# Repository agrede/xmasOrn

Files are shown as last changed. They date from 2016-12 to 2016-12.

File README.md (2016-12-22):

# xmasOrn
Holiday Tree2 Ornament

Tree Ornament with advent calander function. KiCAD files provided and gerber files for making PCB.

## Schematic and Layout
Schematic: [xmasornsch.pdf](https://github.com/agrede/xmasOrn/blob/master/xmasornsch.pdf)
Layout: [xmasornpcb.pdf](https://github.com/agrede/xmasOrn/blob/master/xmasornpcb.pdf)

Resistor values change depending on LED used.

### Minor bugs
The reset button needs to be a normally off switch. Shorting pins removing U2 (NC7WZ14) and shorting the pads for pins 4,5,6 removes the reset.

## Finished Ornament
video demo (http://www.youtube.com/watch?v=HeA6XnS5Pd0)

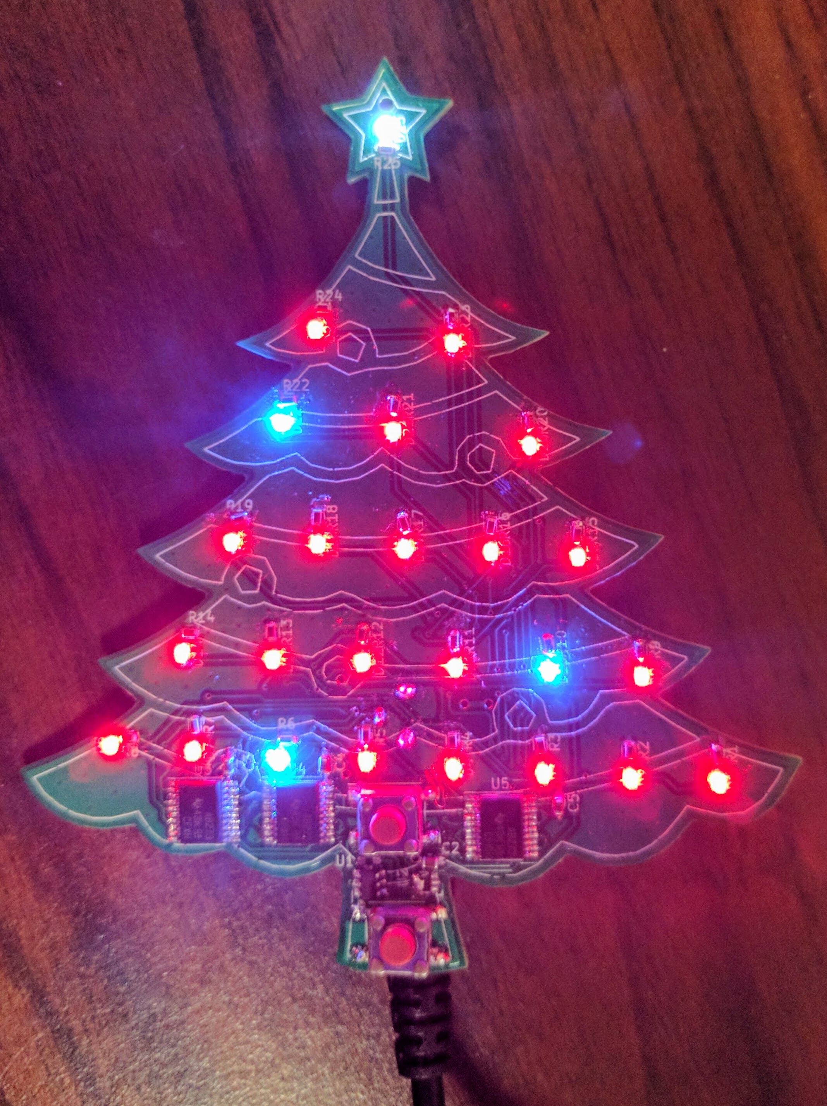
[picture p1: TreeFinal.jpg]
finished ornament


## Licence

<br />This work is licensed under a <a rel="license" href="http://creativecommons.org/licenses/by-sa/4.0/">Creative Commons Attribution-ShareAlike 4.0 International License</a>.

Original Lineart (CC0):
https://pixabay.com/en/christmas-tree-christmas-tree-917749/

3D models, datasheets, etc. are included for convenience

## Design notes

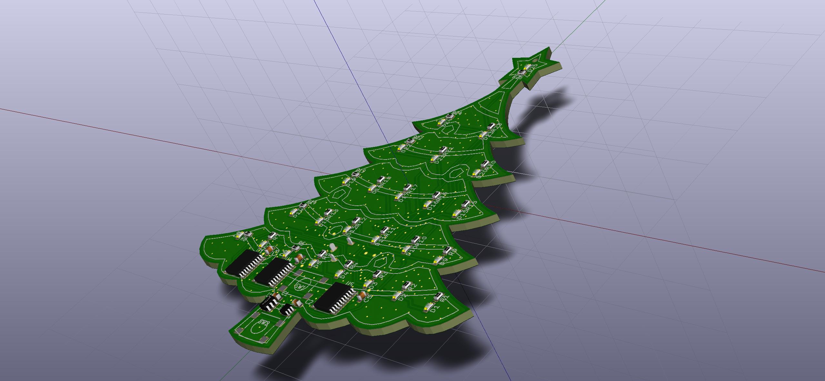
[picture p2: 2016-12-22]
xmasOrn.jpg

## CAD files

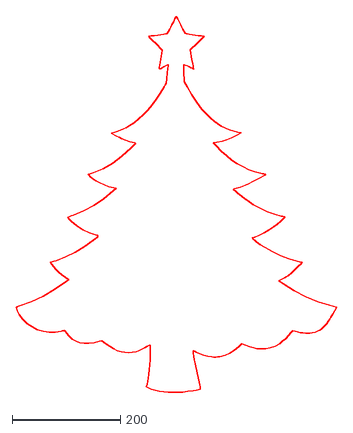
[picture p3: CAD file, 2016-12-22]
christmas-917749.ai.dxf
591.7 x 694.5

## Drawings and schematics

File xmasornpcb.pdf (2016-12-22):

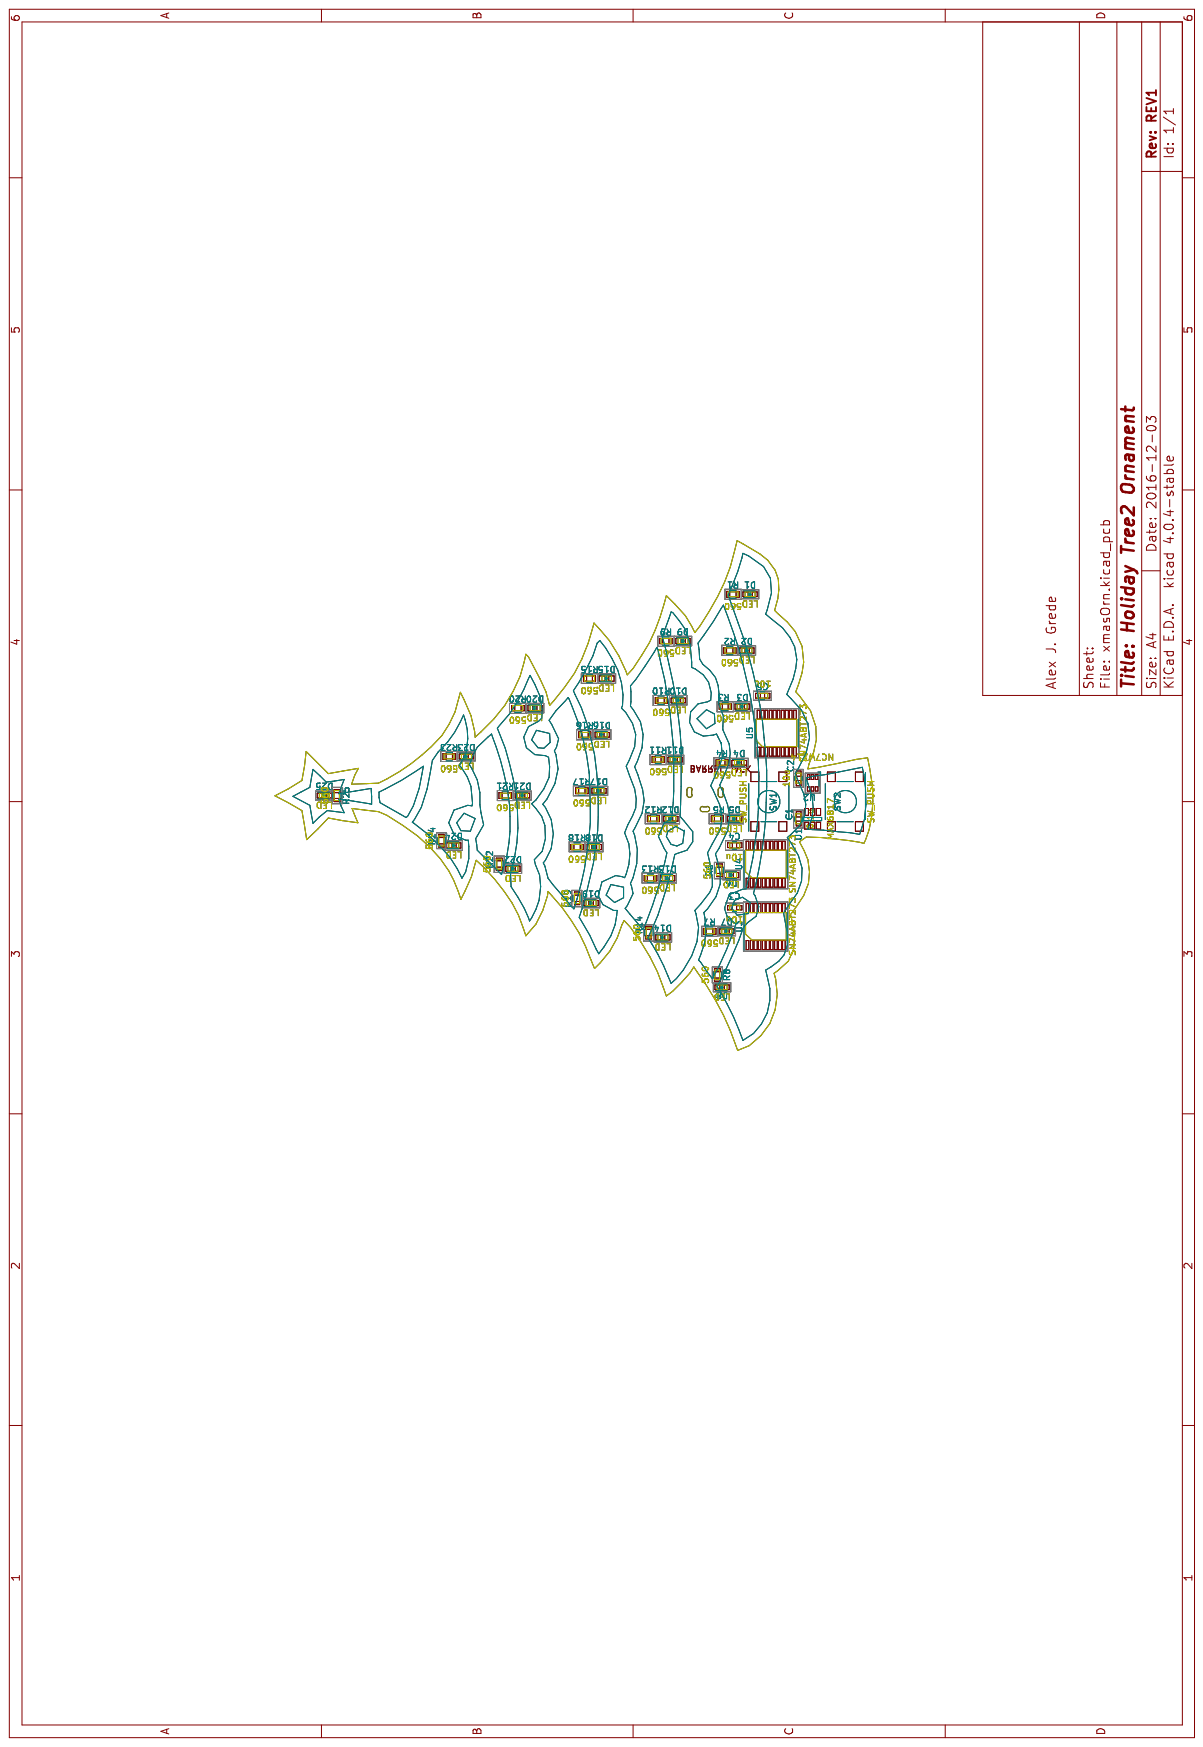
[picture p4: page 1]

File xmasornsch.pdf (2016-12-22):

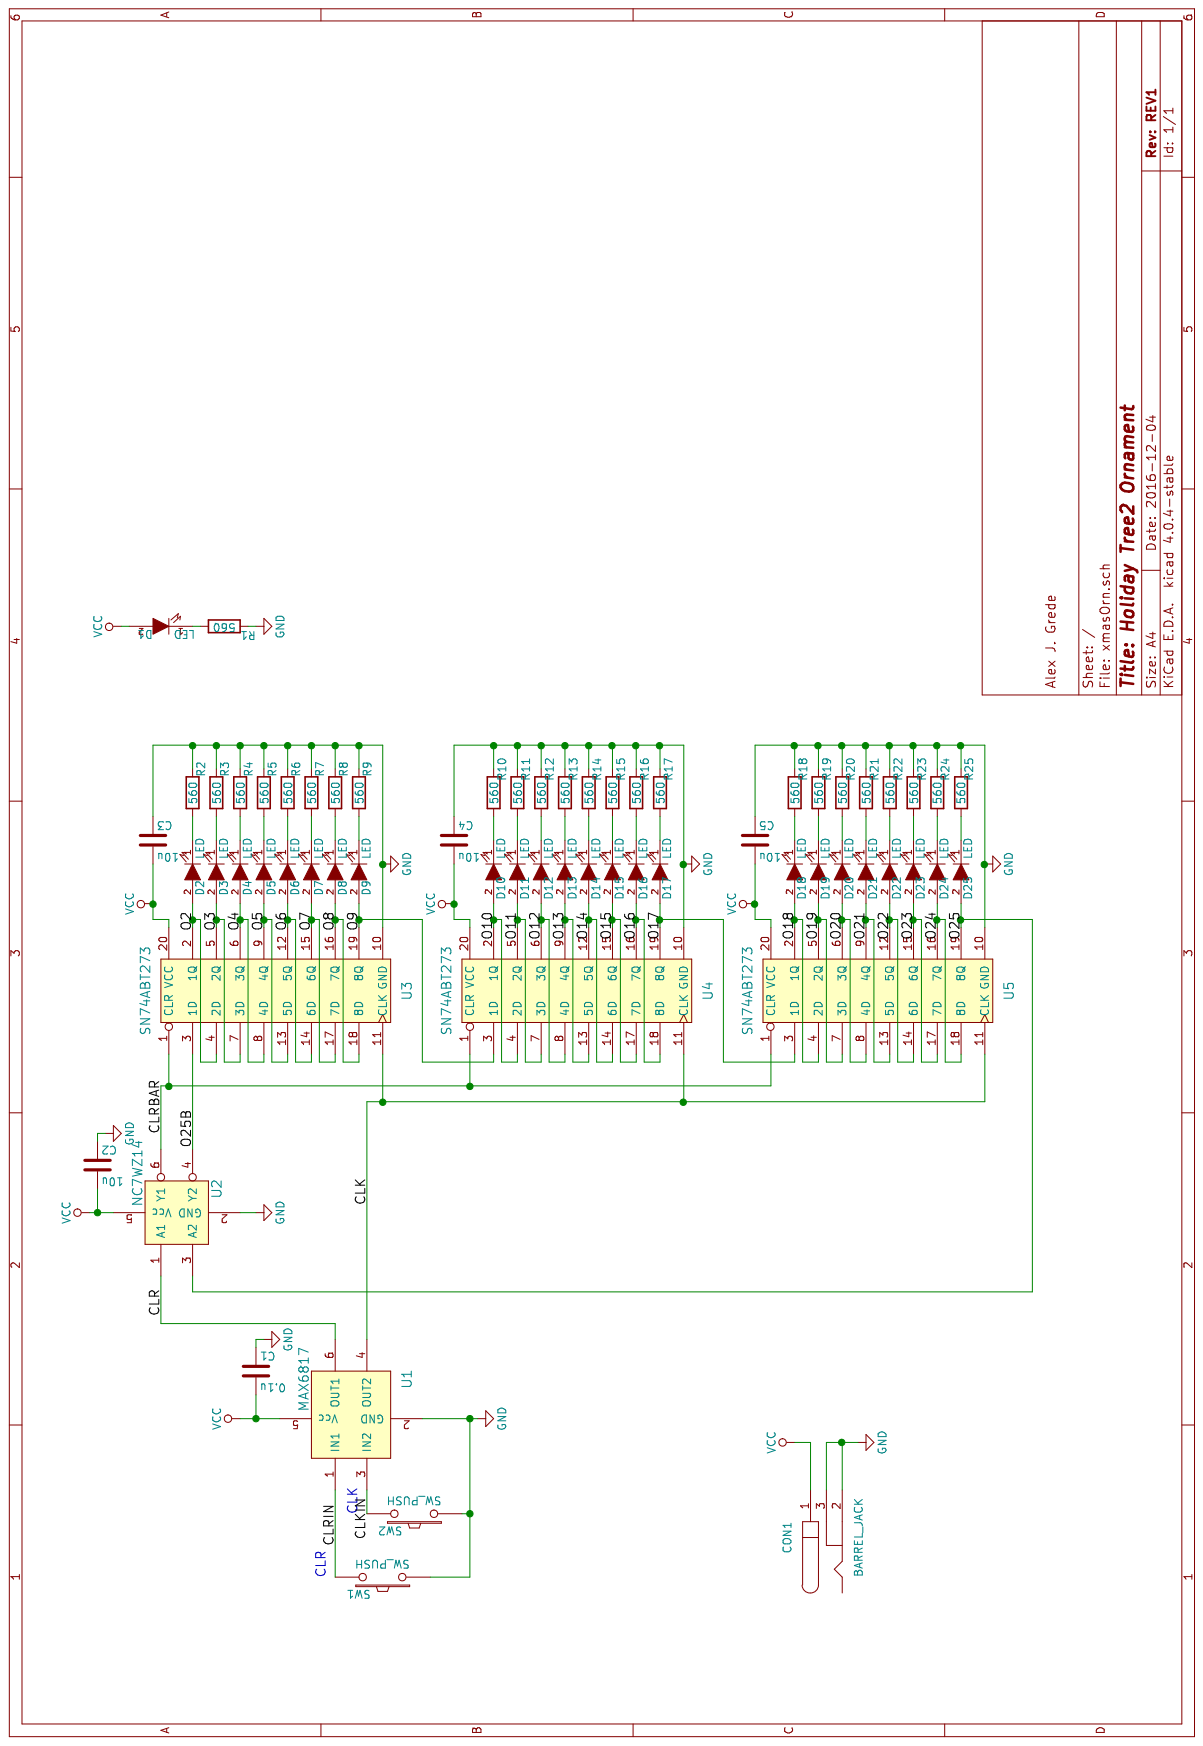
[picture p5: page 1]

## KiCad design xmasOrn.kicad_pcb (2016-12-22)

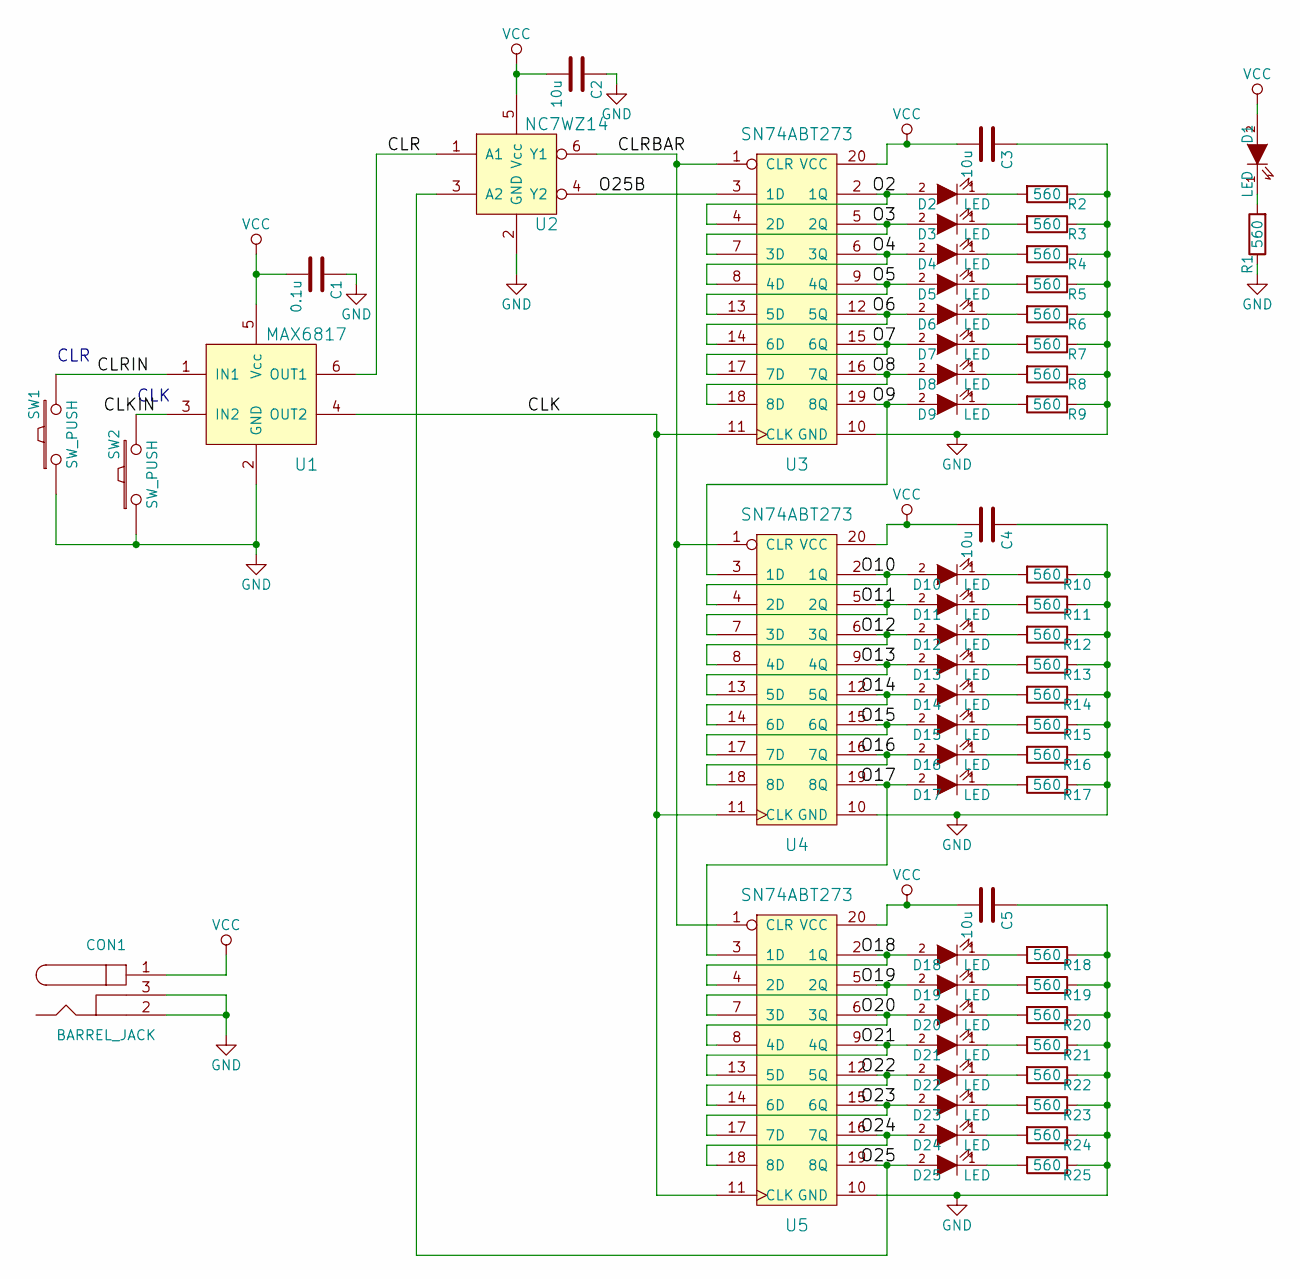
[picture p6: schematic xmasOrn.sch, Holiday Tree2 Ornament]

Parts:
C1: 0.1u; C_0603; Tolerance 20%; Voltage 15V
C2: 10u; C_0603; Tolerance 20%; Voltage 15V
C3, C4, C5: 10u; C_0603
CON1: BARREL_JACK; PJ-007
D1, D2, D3, D4, D5, D6, D7, D8, D9, D10, D11, D12, D13, D14, D15, D16, D17, D18, D19, D20, D21, D22, D23, D24, D25: LED; LED_0603
R1, R2, R3, R4, R5, R6, R7, R8, R9, R10, R11, R12, R13, R14, R15, R16, R17, R18, R19, R20, R21, R22, R23, R24, R25: 560; R_0603
SW1, SW2: SW_PUSH; ADTSM6
U1: MAX6817; SOT-23-6
U2: NC7WZ14; SC-70-6
U3, U4, U5: SN74ABT273; TSSOP-20_4.4x6.5mm_Pitch0.65mm

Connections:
/CLK: U1.4 (OUT2), U3.11 (CLK), U4.11 (CLK), U5.11 (CLK)
/CLKIN: SW2.2, U1.3 (IN2)
/CLR: U1.6 (OUT1), U2.1 (A1)
/CLRBAR: U2.6 (Y1), U3.1 (CLR), U4.1 (CLR), U5.1 (CLR)
/CLRIN: SW1.2, U1.1 (IN1)
/O2: D2.2 (A), U3.2 (1Q), U3.4 (2D)
/O3: D3.2 (A), U3.5 (2Q), U3.7 (3D)
/O4: D4.2 (A), U3.6 (3Q), U3.8 (4D)
/O5: D5.2 (A), U3.9 (4Q), U3.13 (5D)
/O6: D6.2 (A), U3.12 (5Q), U3.14 (6D)
/O7: D7.2 (A), U3.15 (6Q), U3.17 (7D)
/O8: D8.2 (A), U3.16 (7Q), U3.18 (8D)
/O9: D9.2 (A), U3.19 (8Q), U4.3 (1D)
/O10: D10.2 (A), U4.2 (1Q), U4.4 (2D)
/O11: D11.2 (A), U4.5 (2Q), U4.7 (3D)
/O12: D12.2 (A), U4.6 (3Q), U4.8 (4D)
/O13: D13.2 (A), U4.9 (4Q), U4.13 (5D)
/O14: D14.2 (A), U4.12 (5Q), U4.14 (6D)
/O15: D15.2 (A), U4.15 (6Q), U4.17 (7D)
/O16: D16.2 (A), U4.16 (7Q), U4.18 (8D)
/O17: D17.2 (A), U4.19 (8Q), U5.3 (1D)
/O18: D18.2 (A), U5.2 (1Q), U5.4 (2D)
/O19: D19.2 (A), U5.5 (2Q), U5.7 (3D)
/O20: D20.2 (A), U5.6 (3Q), U5.8 (4D)
/O21: D21.2 (A), U5.9 (4Q), U5.13 (5D)
/O22: D22.2 (A), U5.12 (5Q), U5.14 (6D)
/O23: D23.2 (A), U5.15 (6Q), U5.17 (7D)
/O24: D24.2 (A), U5.16 (7Q), U5.18 (8D)
/O25: D25.2 (A), U2.3 (A2), U5.19 (8Q)
/O25B: U2.4 (Y2), U3.3 (1D)
GND: C1.1, C2.1, C3.1, C4.1, C5.1, CON1.2, CON1.3, R1.1, R2.1, R3.1, R4.1, R5.1, R6.1, R7.1, R8.1, R9.1, R10.1, R11.1, R12.1, R13.1, R14.1, R15.1, R16.1, R17.1, R18.1, R19.1, R20.1, R21.1, R22.1, R23.1, R24.1, R25.1, SW1.1, SW2.1, U1.2 (GND), U2.2 (GND), U3.10 (GND), U4.10 (GND), U5.10 (GND)
unnamed: D1.1 (K), R1.2
unnamed: D2.1 (K), R2.2
unnamed: D3.1 (K), R3.2
unnamed: D4.1 (K), R4.2
unnamed: D5.1 (K), R5.2
unnamed: D6.1 (K), R6.2
unnamed: D7.1 (K), R7.2
unnamed: D8.1 (K), R8.2
unnamed: D9.1 (K), R9.2
unnamed: D10.1 (K), R10.2
unnamed: D11.1 (K), R11.2
unnamed: D12.1 (K), R12.2
unnamed: D13.1 (K), R13.2
unnamed: D14.1 (K), R14.2
unnamed: D15.1 (K), R15.2
unnamed: D16.1 (K), R16.2
unnamed: D17.1 (K), R17.2
unnamed: D18.1 (K), R18.2
unnamed: D19.1 (K), R19.2
unnamed: D20.1 (K), R20.2
unnamed: D21.1 (K), R21.2
unnamed: D22.1 (K), R22.2
unnamed: D23.1 (K), R23.2
unnamed: D24.1 (K), R24.2
unnamed: D25.1 (K), R25.2
VCC: C1.2, C2.2, C3.2, C4.2, C5.2, CON1.1, D1.2 (A), U1.5 (Vcc), U2.5 (Vcc), U3.20 (VCC), U4.20 (VCC), U5.20 (VCC)

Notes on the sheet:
CLR
CLK

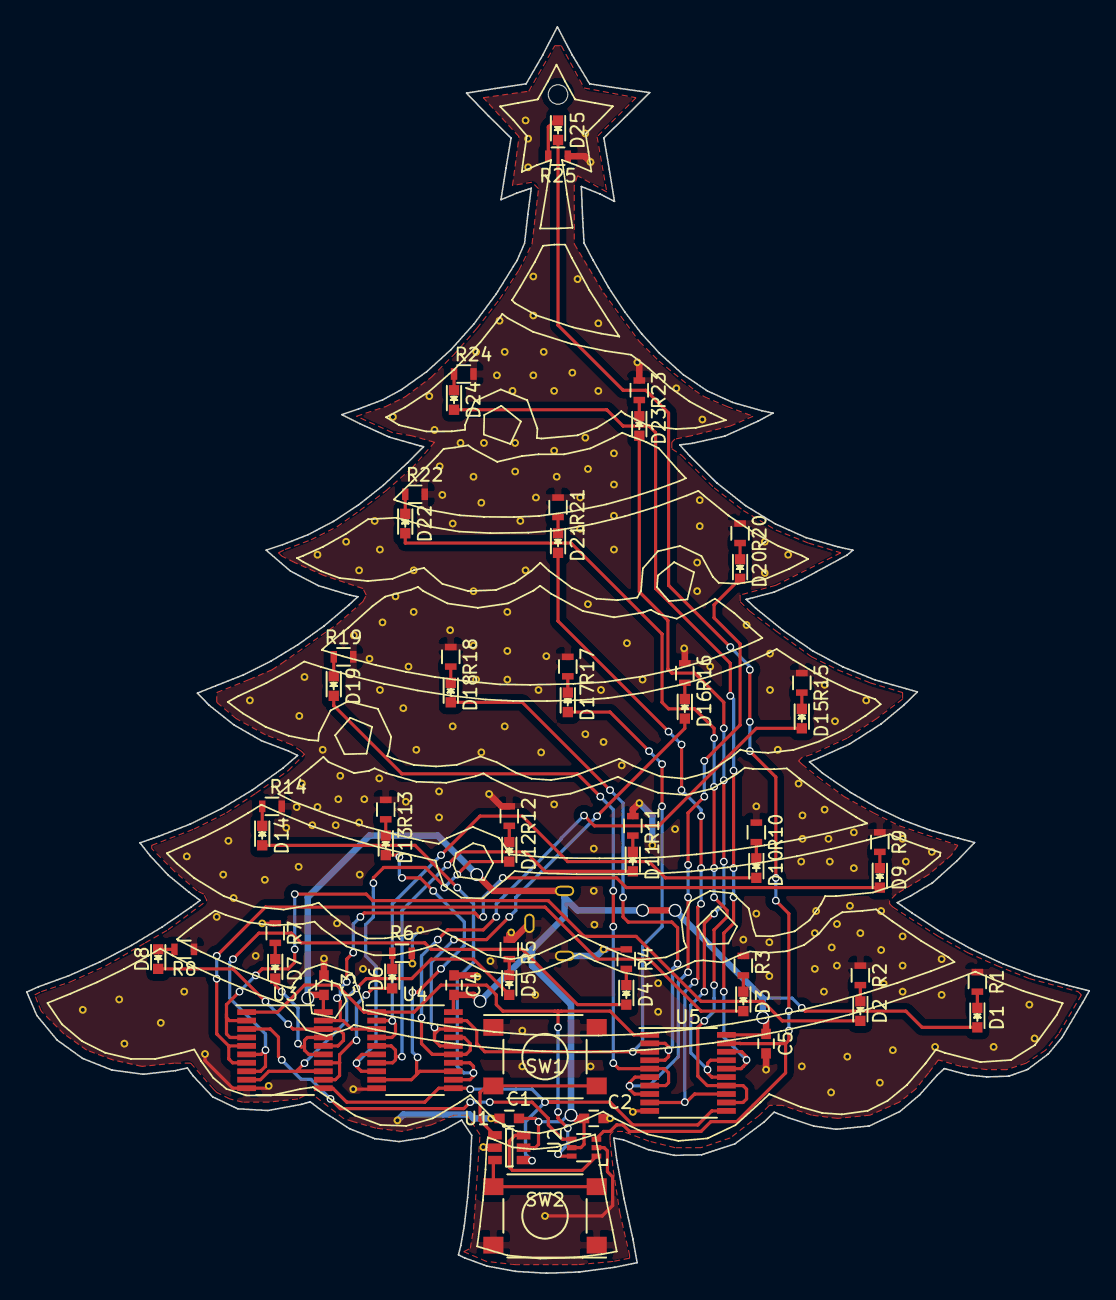
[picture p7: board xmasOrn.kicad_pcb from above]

Board: 2 copper layers, 81.7 x 95.9 mm, 64 parts (1 on the bottom side), 57 nets.

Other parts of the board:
svg2mod: G***; xmastreeSS
